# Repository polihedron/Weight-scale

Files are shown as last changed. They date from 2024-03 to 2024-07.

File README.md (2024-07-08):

# Weight-scale
Simple weight scale made on request to control baby weight increase. 
<br>

<br>

features:
- 2.8" LCD with touch screen
- sensor calibration (manual)
- save calibration data to memory
- restore factory calibration data
- touch the result on display to tare
- 20kg sensor
- fast TouchGFX app (LL SPI with DMA) 
- usb c charging port

<br>

future improvements:
- usb pendrive log data
- environmental sensor to measure relative humidity, barometric pressure and ambient temperature
- RTC module
- automatic calibration
- battery status
- screen auto brightness

3D files:
https://www.thingiverse.com/thing:6554794

<br><br>
set

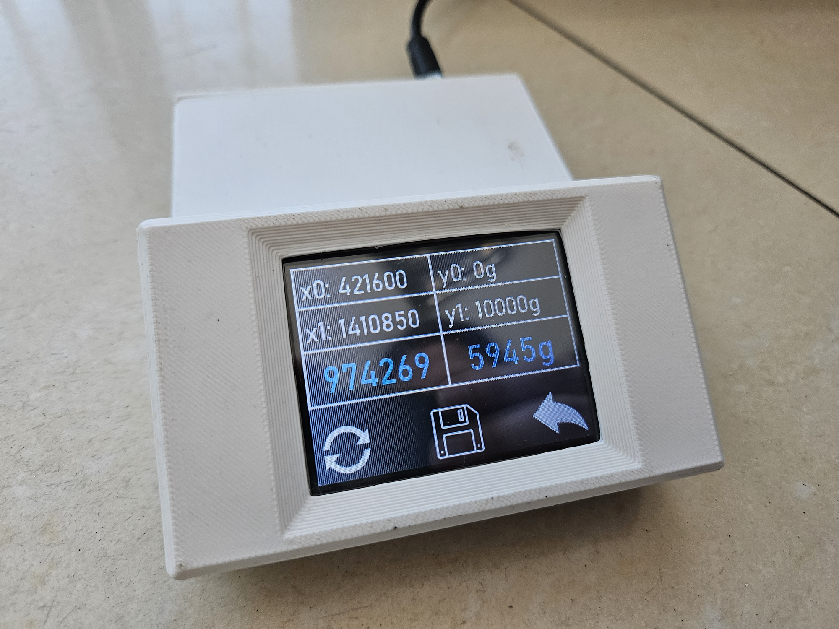
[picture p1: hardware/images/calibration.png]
calibration


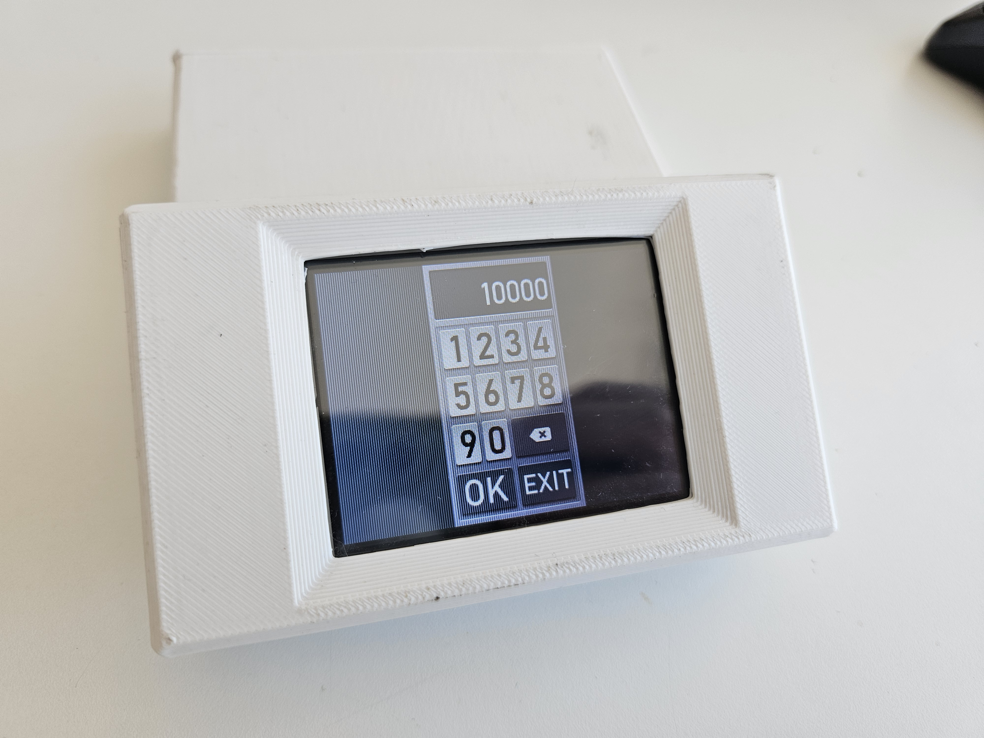
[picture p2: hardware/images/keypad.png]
keypad


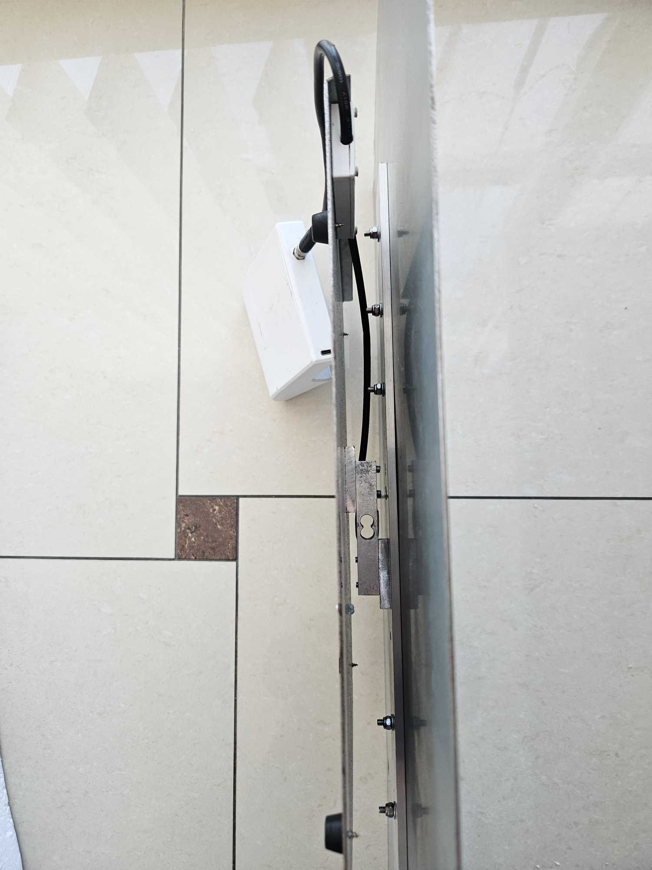
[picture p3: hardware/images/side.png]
side


<br><br><br>
based on:

https://github.com/trteodor/TouchGFX_PortTo_STM32F407_ILI9341_XPT2046

https://www.youtube.com/playlist?list=PLfIJKC1ud8giOsk-C4BCOwSHtbXqTNb1W

https://github.com/ufnalski/hx711_non_blocking_spi_g431kb

https://www.stm32wrobotyce.pl/2023/04/26/proste-filtry-cyfrowe-cz-1-filtr-usredniajacy/

https://www.youtube.com/watch?v=XAcW4c5qIMc

<br><br><br>

BOM:
- WeAct v2 Blackpill STM32F411CEU dev board with soldered U3: FRAM 8kB chip: MB85RS64V (Adafruit 1897)
  
WeAct-BlackPill-STM32F411CEU6
Adafruit 1897

- LCD SPI Display 2.8" ILI9341 controler
  
2-8-240-320-ILI9341

- 20kg sensor with HX711 module
  
  HX711

- 18750 lithium battery 1S2P, or 1S1P with welding cable

  18650-Li-ion

- TPS63020 module
  
XL63020-TPS63020

- TP4056 module
  
TC4056A

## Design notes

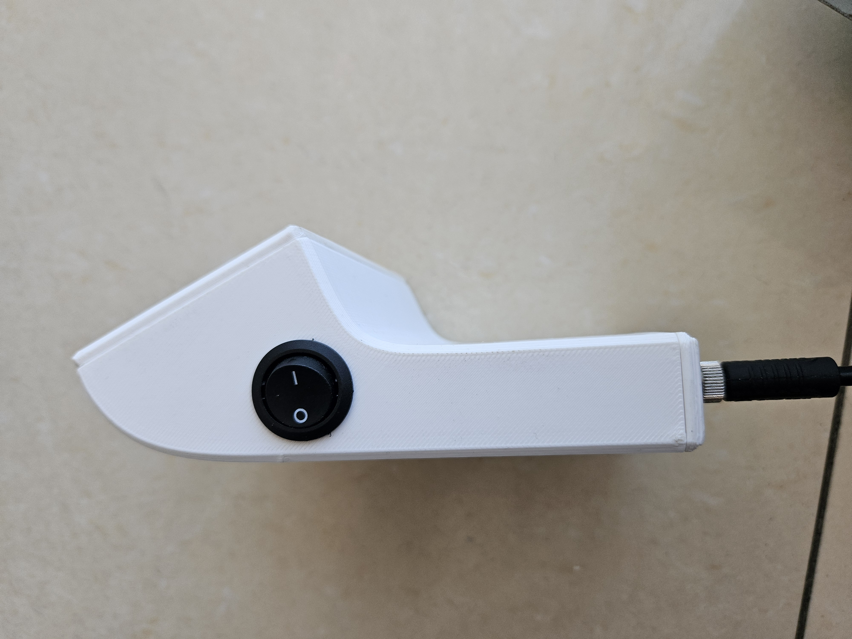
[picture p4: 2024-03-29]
hardware/images/profile.png

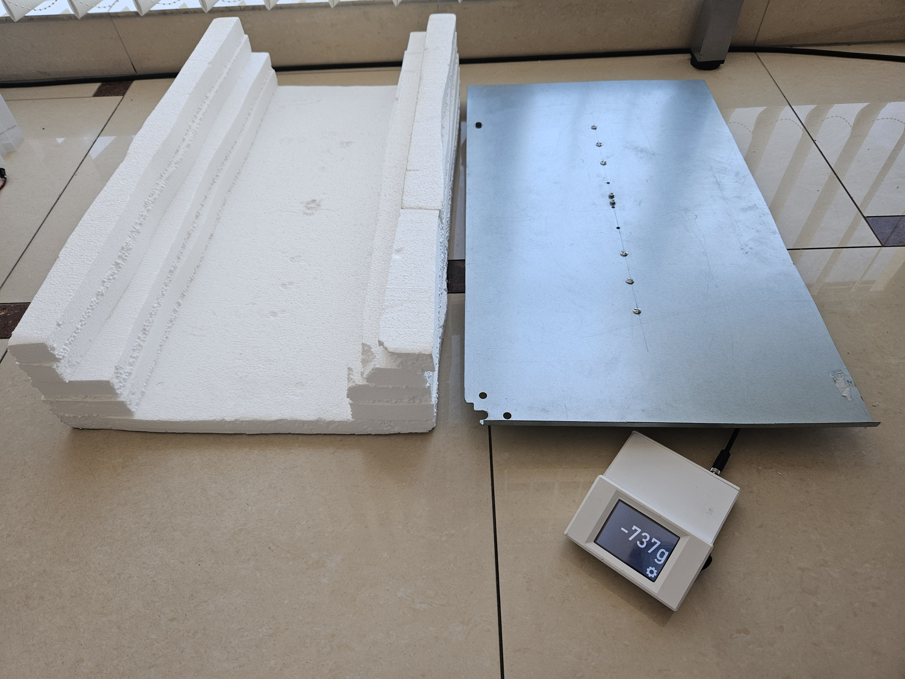
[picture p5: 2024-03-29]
hardware/images/top.png

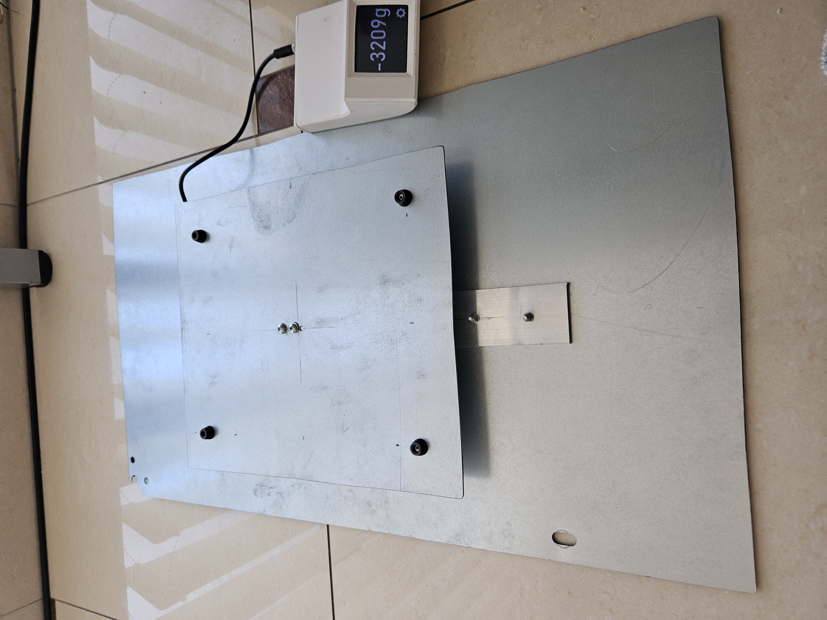
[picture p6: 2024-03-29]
hardware/images/bottom.png

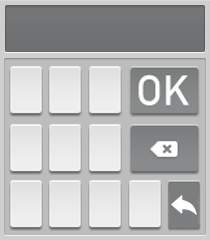
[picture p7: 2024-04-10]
software/STM32F411_ILI9341_HX711/TouchGFX/assets/images/keyboard_background.png

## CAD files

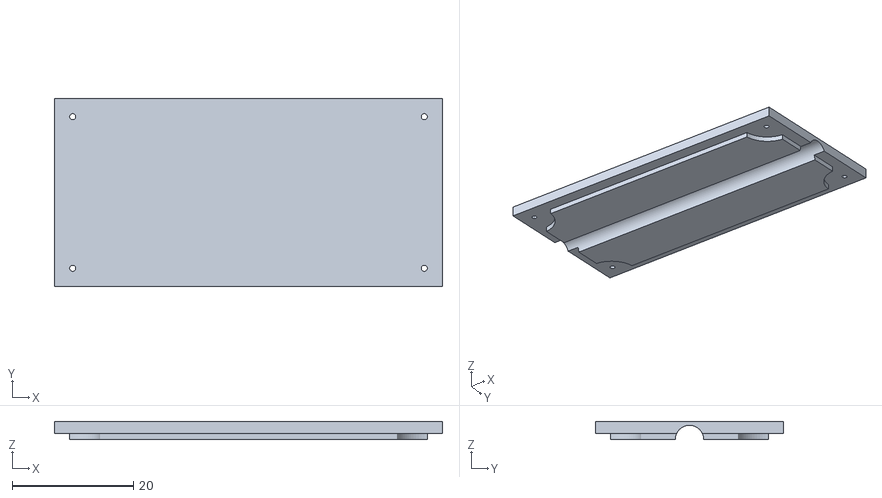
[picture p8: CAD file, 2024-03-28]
hardware/3d_enclosure_model_stl/weight.scale.hx711.top v20.stl
64.0 x 31.0 x 3.00

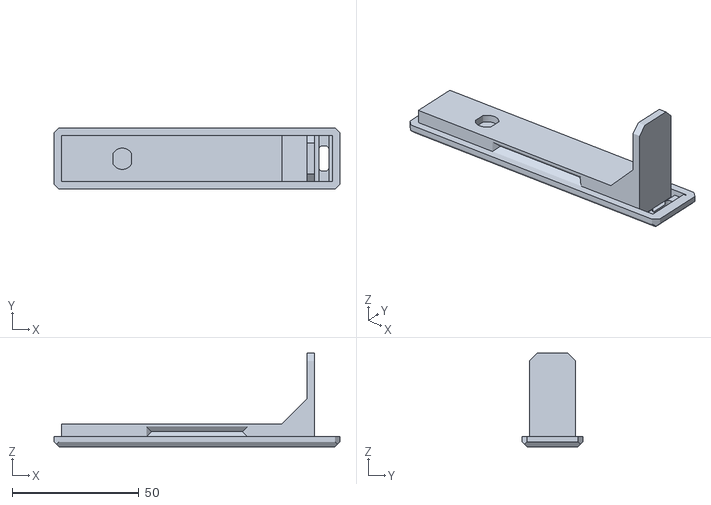
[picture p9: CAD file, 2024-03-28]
hardware/3d_enclosure_model_stl/weight.scale.back v20.stl
113.0 x 24.2 x 37.0

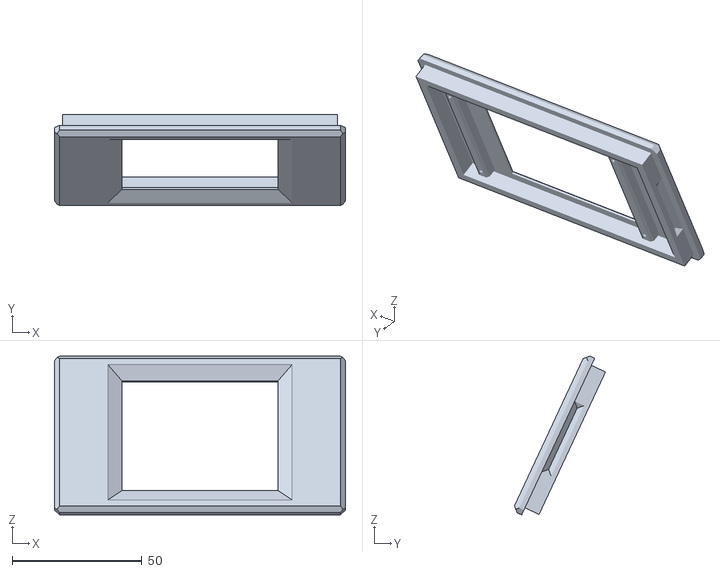
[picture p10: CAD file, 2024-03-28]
hardware/3d_enclosure_model_stl/weight.scale.front v20.stl
112.0 x 35.1 x 61.1

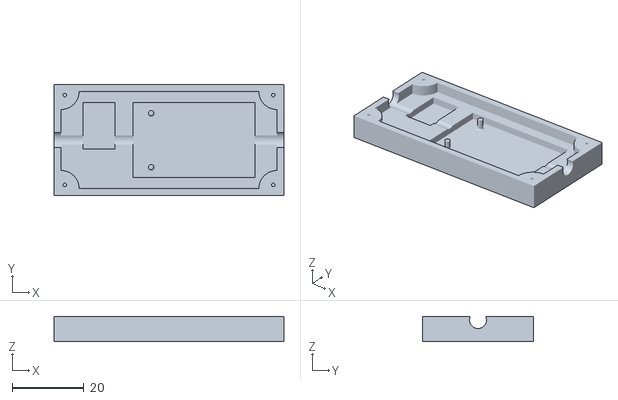
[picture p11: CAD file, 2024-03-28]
hardware/3d_enclosure_model_stl/weight.scale.hx711.bottom v20.stl
64.0 x 31.0 x 7.00

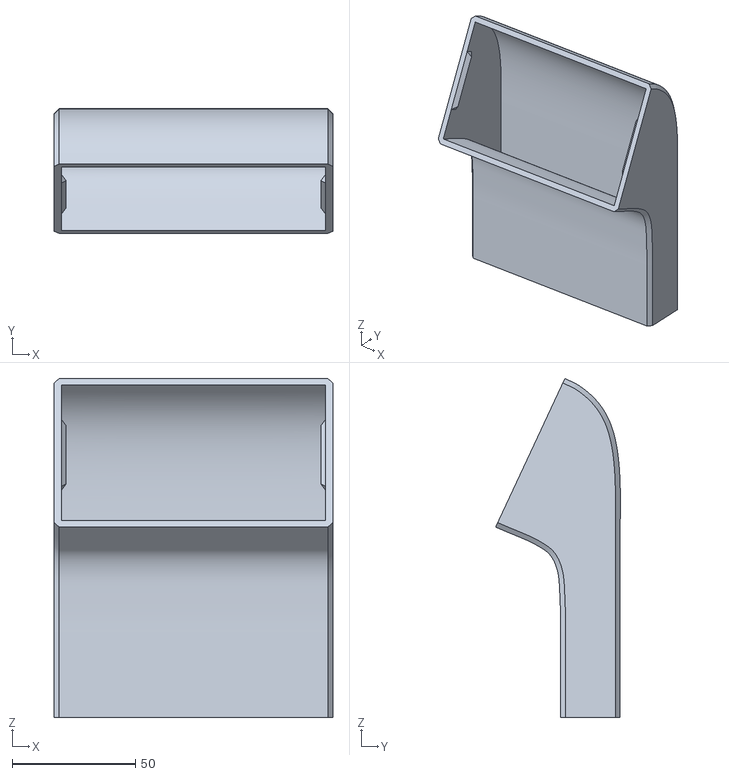
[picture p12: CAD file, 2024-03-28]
hardware/3d_enclosure_model_stl/weight.scale.enclosure v20.stl
113.0 x 50.6 x 137.5

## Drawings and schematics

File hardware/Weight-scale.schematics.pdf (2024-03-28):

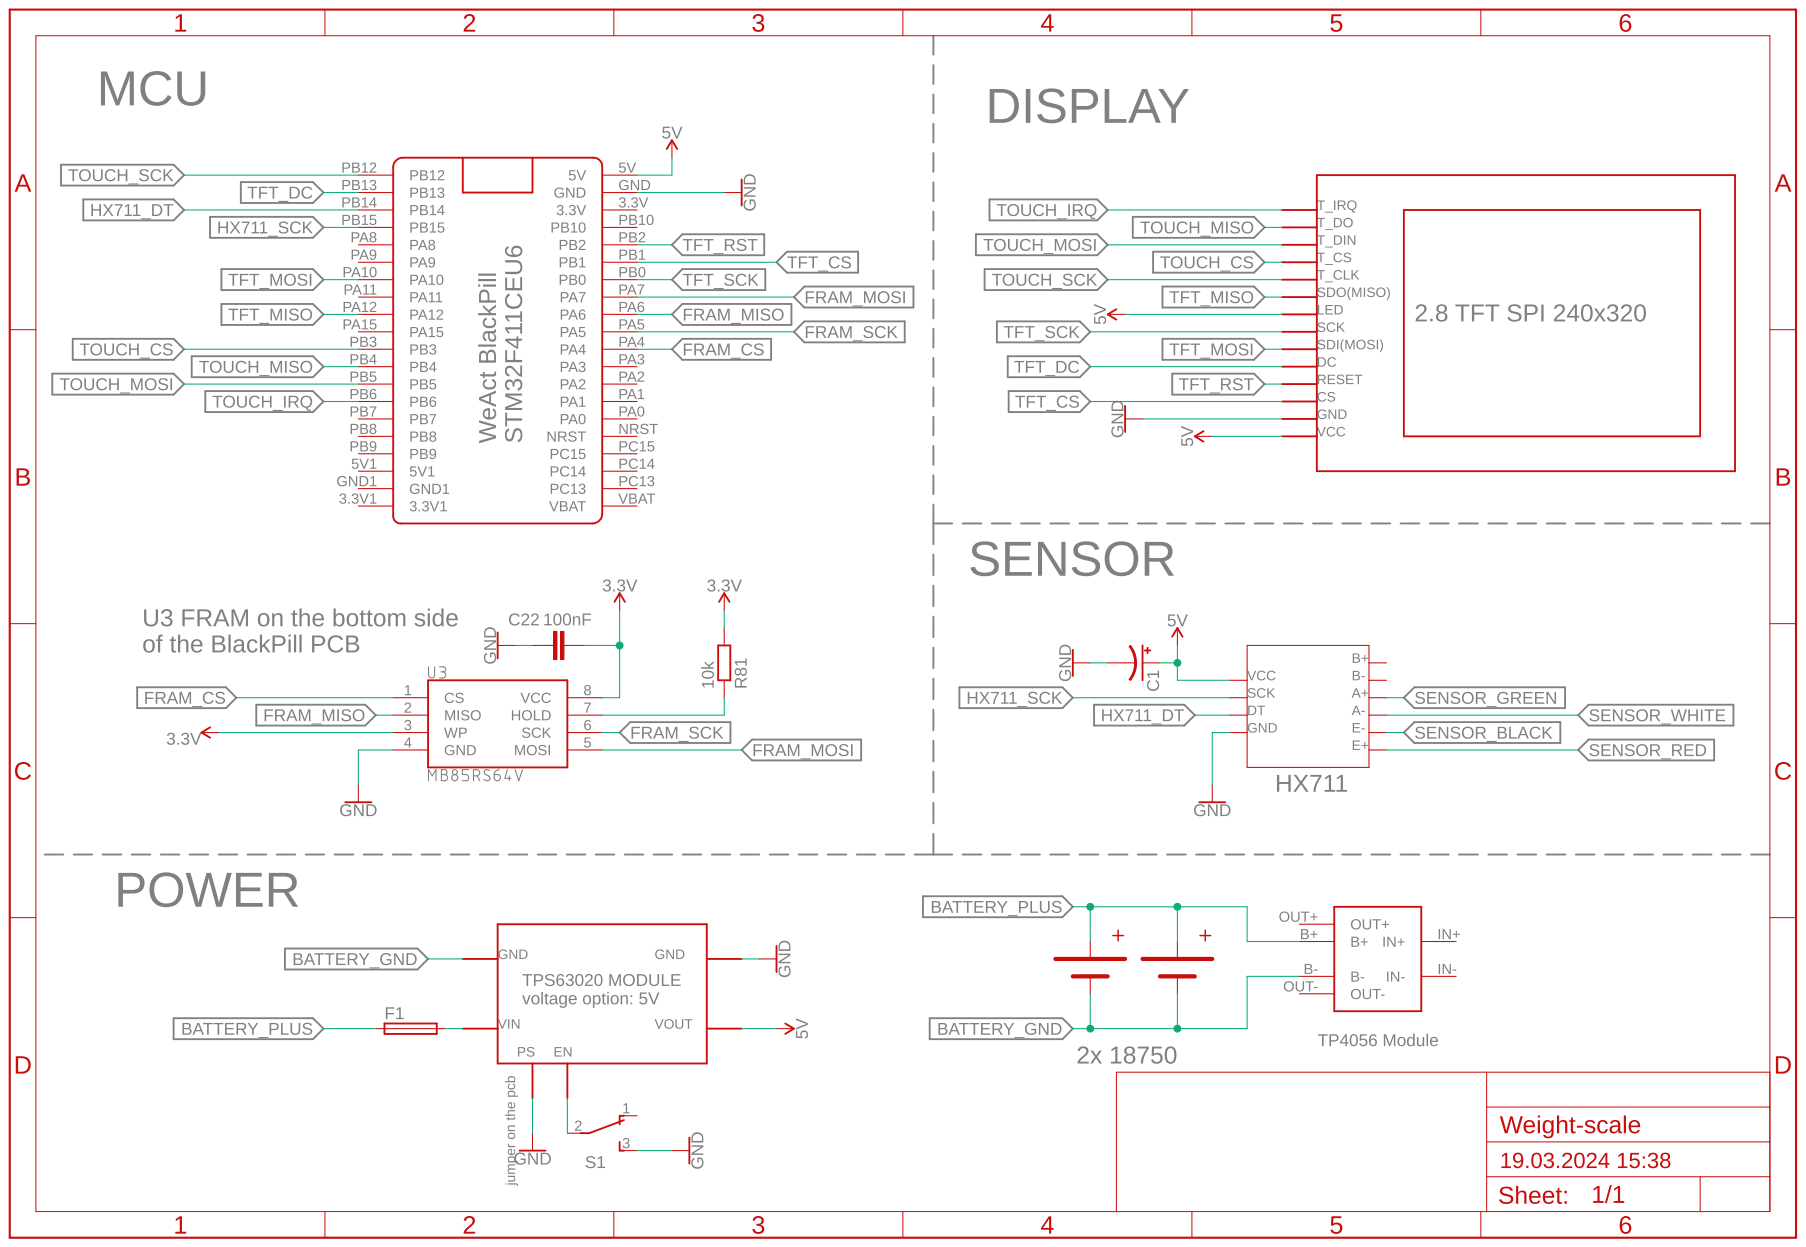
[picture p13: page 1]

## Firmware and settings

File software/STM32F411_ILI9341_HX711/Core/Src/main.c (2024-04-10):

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
/* Includes ------------------------------------------------------------------*/
#include "main.h"
#include "crc.h"
#include "dma.h"
#include "spi.h"
#include "tim.h"
#include "gpio.h"
#include "app_touchgfx.h"

/* USER CODE BEGIN Includes */

#include "../../Drivers/MB85RS64V/fram.h"
#include "../../Drivers/ili9341/core.h"
#include "../../Drivers/XPT2046/XPT2046.h"
#include "simple_filters.h"
#include "math.h"
/* USER CODE END Includes */

/* USER CODE BEGIN PD */
#define FRAM_CS_DISABLE HAL_GPIO_WritePin(FRAM_CS_GPIO_Port, FRAM_CS_Pin, 1)
#define DISPLAY_REFRESH_DELAY_MS 500
/* USER CODE END PD */


/* USER CODE BEGIN PV */

//typedef struct
//{
//	int32_t weight_avg;;
//	uint32_t raw_avg;
//} weight_data_avg_t;

uint8_t TxData[8] = { 0b0000000, 0x00000001, 0b01010101, 0b01010101, 0b01010101, 0b01010101, 0b01010101, 0b01010101 };  // clock, 25 ticks
uint8_t RxData[8];
//uint64_t raw_reading;
uint8_t sensor_read_flag = 0;

int32_t weight_avg;
uint32_t raw_avg;
uint32_t raw_avg_offset;
uint32_t SoftTimer;

//double CalibrationX0 = 0;
//double CalibrationY0 = 0;
//double CalibrationX1 = 0;
//double CalibrationY1 = 0;
uint32_t CalibrationX0 = CALIBRATION_X0;
uint32_t CalibrationY0 = CALIBRATION_Y0;
uint32_t CalibrationX1 = CALIBRATION_X1;
uint32_t CalibrationY1 = CALIBRATION_Y1;

/* USER CODE END PV */

void SystemClock_Config(void);
static void MX_NVIC_Init(void);
/* USER CODE BEGIN PFP */

int32_t get_weight(uint64_t  result);
uint64_t get_raw_weight();
void doMeasure (void);
void doMemories(void);


void HAL_SPI_TxRxCpltCallback(SPI_HandleTypeDef *hspi)
{
	if (hspi->Instance == SPI2)
	{
		sensor_read_flag = 1;
	}
}

/* USER CODE END PFP */

/* USER CODE BEGIN 0 */
extern void touchgfxSignalVSync(void);

void HAL_TIM_PeriodElapsedCallback(TIM_HandleTypeDef *htim)
{
	if (htim->Instance == TIM2) {
		touchgfxSignalVSync();  //i'am dk why but i turned off the vSync in Cube but i still have to get infi :/
	}
}
/* USER CODE END 0 */

/**
  * @brief  The application entry point.
  * @retval int
  */
int main(void)
{
  /* MCU Configuration--------------------------------------------------------*/

  /* Reset of all peripherals, Initializes the Flash interface and the Systick. */
  HAL_Init();

  /* Configure the system clock */
  SystemClock_Config();

  /* USER CODE BEGIN SysInit */

  FRAM_CS_DISABLE;

  /* USER CODE END SysInit */

  /* Initialize all configured peripherals */
  MX_GPIO_Init();
  MX_DMA_Init();
  MX_SPI1_Init();
  MX_SPI2_Init();
  MX_SPI3_Init();
  MX_TIM2_Init();
  MX_CRC_Init();
  MX_SPI5_Init();
  MX_TouchGFX_Init();

  /* Initialize interrupts */
  MX_NVIC_Init();
  /* USER CODE BEGIN 2 */
  setSPI_FRAM_Handle(&hspi1);
  FRAM_init();
  doMemories();
  HAL_TIM_Base_Start_IT(&htim2);
  ILI9341_Init();
  XPT2046_Init(&hspi3, EXTI9_5_IRQn);
  touchgfxSignalVSync();

//  DoCalibration();

  HAL_SPI_TransmitReceive_DMA(&hspi2, (uint8_t*) (&TxData),(uint8_t*) (&RxData), sizeof(TxData));
  SoftTimer = HAL_GetTick();
  filter_moving_average_init();
  filter_median_init();
  raw_avg_offset = CalibrationX0;
  /* USER CODE END 2 */

  /* Infinite loop */
  /* USER CODE BEGIN WHILE */
  while (1)
  {

	  XPT2046_Task();

	  doMeasure();

    /* USER CODE END WHILE */

  MX_TouchGFX_Process();
    /* USER CODE BEGIN 3 */
  }
  /* USER CODE END 3 */
}

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
/* USER CODE BEGIN 4 */


void HAL_GPIO_EXTI_Callback(uint16_t GPIO_Pin)
{
	if(GPIO_Pin == TOUCH_IRQ_Pin)
	{
		XPT2046_IRQ();
	}

}
void doMemories(void)	{

//	typedef union
//	{
//	    uint32_t split[2];
//	    double d_value;
//	} split_double;
//	split_double cx0 = {0};
//	split_double cy0 = {0};
//	split_double cx1 = {0};
//	split_double cy1 = {0};

	uint32_t cx0_value;
	uint32_t cy0_value;
	uint32_t cx1_value;
	uint32_t cy1_value;

	uint8_t memory_init = FRAM_read8(0x0000);
	if (memory_init != 0xCC)	{
		FRAM_write8(0x0000, 0xCC);
		cx0_value = CalibrationX0;
		cy0_value = CalibrationY0;
		cx1_value = CalibrationX1;
		cy1_value = CalibrationY1;
		FRAM_write32(0x0001, cx0_value);
		FRAM_write32(0x0005, cy0_value);
		FRAM_write32(0x0009, cx1_value);
		FRAM_write32(0x000D, cy1_value);
//		FRAM_write32(0x0011, cx1.split[0]);
//		FRAM_write32(0x0015, cx1.split[1]);
//		FRAM_write32(0x0019, cy1.split[0]);
//		FRAM_write32(0x001D, cy1.split[1]);
	}

	else	{

		cx0_value = FRAM_read32(0x0001);
		cy0_value = FRAM_read32(0x0005);
		cx1_value = FRAM_read32(0x0009);
		cy1_value = FRAM_read32(0x000D);
//		cx1.split[0] = FRAM_read32(0x0011);
//		cx1.split[1] = FRAM_read32(0x0015);
//		cy1.split[0] = FRAM_read32(0x0019);
//		cy1.split[1] = FRAM_read32(0x001D);

		CalibrationX0 = cx0_value;
		CalibrationY0 = cy0_value;
		CalibrationX1 = cx1_value;
		CalibrationY1 = cy1_value;
	}


}

void saveMemories(void)	{

//	typedef union
//	{
//	    uint32_t split[2];
//	    double d_value;
//	} split_double;
//	split_double cx0 = {0};
//	split_double cy0 = {0};
//	split_double cx1 = {0};
//	split_double cy1 = {0};
//	cx0.d_value = CalibrationX0;
//	cy0.d_value = CalibrationY0;
//	cx1.d_value = CalibrationX1;
//	cy1.d_value = CalibrationY1;

	uint32_t  cx0_value = CalibrationX0;
	uint32_t  cy0_value = CalibrationY0;
	uint32_t  cx1_value = CalibrationX1;
	uint32_t  cy1_value = CalibrationY1;


	uint8_t memory_init = FRAM_read8(0x0000);
	if (memory_init == 0xCC)	{
		//FRAM_write8(0x0000, 0xCC);
		FRAM_write32(0x0001, cx0_value);
		FRAM_write32(0x0005, cy0_value);
		FRAM_write32(0x0009, cx1_value);
		FRAM_write32(0x000D, cy1_value);
//		FRAM_write32(0x0011, cx1.split[0]);
//		FRAM_write32(0x0015, cx1.split[1]);
//		FRAM_write32(0x0019, cy1.split[0]);
//		FRAM_write32(0x001D, cy1.split[1]);
	}

}


void doMeasure (void) {

	int32_t weight_avg_temp;
	uint32_t raw_avg_temp;

	if (sensor_read_flag == 1)
	{
		//get_raw_weight( &raw );
		raw_avg_temp = filter_moving_average(get_raw_weight());
		weight_avg_temp  = filter_median(get_weight(raw_avg)- get_weight(raw_avg_offset));
	}


	if ((sensor_read_flag == 1) && (HAL_GPIO_ReadPin(SPI2_MISO_GPIO_Port, SPI2_MISO_Pin) == GPIO_PIN_RESET))
	{
		sensor_read_flag = 0;
		HAL_SPI_TransmitReceive_DMA(&hspi2, (uint8_t*) (&TxData), (uint8_t*) (&RxData), sizeof(TxData));
	}

	if ((HAL_GetTick() - SoftTimer) > DISPLAY_REFRESH_DELAY_MS) {

		raw_avg = raw_avg_temp;

		if	(weight_avg_temp > (SENSOR_MAXIMUM_IN_GRAM - LOAD_PLATFORM_WEIGHT_IN_GRAM)  )
		{
			weight_avg = SENSOR_MAXIMUM_IN_GRAM - LOAD_PLATFORM_WEIGHT_IN_GRAM;
		}
		else
		{
			weight_avg  = weight_avg_temp;
		}

		SoftTimer = HAL_GetTick();
	 }

}



uint64_t get_raw_weight()	{

	uint64_t raw_reading = (((uint64_t) (RxData[7] & 0b00000010)) >> 1)
	| (((uint64_t) (RxData[7] & 0b00001000)) >> 2)
	| (((uint64_t) (RxData[7] & 0b00100000)) >> 3)
	| (((uint64_t) (RxData[7] & 0b10000000)) >> 4)
	| (((uint64_t) (RxData[6] & 0b00000010)) << 3)
	| (((uint64_t) (RxData[6] & 0b00001000)) << 2)
	| (((uint64_t) (RxData[6] & 0b00100000)) << 1)
	| (((uint64_t) (RxData[6] & 0b10000000)) << 0) |

	(((uint64_t) (RxData[5] & 0b00000010)) << 7)
	| (((uint64_t) (RxData[5] & 0b00001000)) << 6)
	| (((uint64_t) (RxData[5] & 0b00100000)) << 5)
	| (((uint64_t) (RxData[5] & 0b10000000)) << 4)
	| (((uint64_t) (RxData[4] & 0b00000010)) << 11)
	| (((uint64_t) (RxData[4] & 0b00001000)) << 10)
	| (((uint64_t) (RxData[4] & 0b00100000)) << 9)
	| (((uint64_t) (RxData[4] & 0b10000000)) << 8) |

	(((uint64_t) (RxData[3] & 0b00000010)) << 15)
	| (((uint64_t) (RxData[3] & 0b00001000)) << 14)
	| (((uint64_t) (RxData[3] & 0b00100000)) << 13)
	| (((uint64_t) (RxData[3] & 0b10000000)) << 12)
	| (((uint64_t) (RxData[2] & 0b00000010)) << 19)
	| (((uint64_t) (RxData[2] & 0b00001000)) << 18)
	| (((uint64_t) (RxData[2] & 0b00100000)) << 17)
	| (((uint64_t) (RxData[2] & 0b10000000)) << 16) |

	(((uint64_t) (RxData[1] & 0b00000010)) << 23)
	| (((uint64_t) (RxData[1] & 0b00001000)) << 22)
	| (((uint64_t) (RxData[1] & 0b00100000)) << 21)
	| (((uint64_t) (RxData[1] & 0b10000000)) << 20);

return raw_reading;
}



int32_t get_weight(uint64_t  raw_reading )	{

	int32_t result = round (((double)CalibrationY1 - CalibrationY0) / (CalibrationX1 - CalibrationX0) * ((double)raw_reading - CalibrationX1) + CalibrationY1);
	return result;
}




/* USER CODE END 4 */
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


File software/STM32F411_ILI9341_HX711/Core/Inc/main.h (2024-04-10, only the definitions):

#define LED_Pin GPIO_PIN_13
#define LED_GPIO_Port GPIOC
#define FRAM_CS_Pin GPIO_PIN_4
#define FRAM_CS_GPIO_Port GPIOA
#define SPI1_MISO_Pin GPIO_PIN_6
#define SPI1_MISO_GPIO_Port GPIOA
#define SPI1_MOSI_Pin GPIO_PIN_7
#define SPI1_MOSI_GPIO_Port GPIOA
#define TFT_CS_Pin GPIO_PIN_1
#define TFT_CS_GPIO_Port GPIOB
#define TFT_RST_Pin GPIO_PIN_2
#define TFT_RST_GPIO_Port GPIOB
#define TFT_DC_Pin GPIO_PIN_13
#define TFT_DC_GPIO_Port GPIOB
#define SPI2_MISO_Pin GPIO_PIN_14
#define SPI2_MISO_GPIO_Port GPIOB
#define TOUCH_CS_Pin GPIO_PIN_3
#define TOUCH_CS_GPIO_Port GPIOB
#define TOUCH_IRQ_Pin GPIO_PIN_6
#define TOUCH_IRQ_GPIO_Port GPIOB
#define TOUCH_IRQ_EXTI_IRQn EXTI9_5_IRQn
#define CALIBRATION_X1 1410850
#define CALIBRATION_Y1 10000
#define CALIBRATION_X0 421600
#define CALIBRATION_Y0 0
#define SENSOR_MAXIMUM_IN_GRAM	20000
#define LOAD_PLATFORM_WEIGHT_IN_GRAM	5000

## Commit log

2024-03-28 connections diagram, 3D enclosure
    [weight.scale.back v20.stl, weight.scale.enclosure v20.stl, weight.scale.front v20.stl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]
2024-03-28 initial, working.
    [texts.xlsx]
2024-04-04 filtering ref.
2024-04-04 median and moving average filtering
2024-04-04 filtering refact.
2024-04-10 sensor data measure refactoring
2024-04-10 new, bigger keypad, small fixes
    [NumericKeyboardLayout.hpp]

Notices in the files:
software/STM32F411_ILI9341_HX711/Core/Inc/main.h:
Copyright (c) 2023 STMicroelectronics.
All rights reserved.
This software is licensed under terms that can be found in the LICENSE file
